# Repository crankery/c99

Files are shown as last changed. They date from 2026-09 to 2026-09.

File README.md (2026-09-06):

# Mini Mini Cortex 

***Note: Do not build this thing, I am just experimenting.***

Just a silly project really. Trying to squeeze Stuart Conner's [Mini Cortex](https://www.stuartconner.me.uk/mini_cortex/mini_cortex.htm) down
to a smaller form factor. Really, for no good reason.

I am going to attempt to add a different storage mechanism as CF cards are a bit hard to work with these days. To this end, there's an expansion
connector on this thing which is intended to have a stack of expansions plugged in from below.

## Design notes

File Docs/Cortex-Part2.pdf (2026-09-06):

# PROJECT

# CORTEX PART 2

# Build yourself a better brain: this month we explain the remaining Cortex circuitry and the construction of the main

board.

### Serial I/O on the Cortex is handled by a versatile

UART, the 9902. The CPU

### communicates with the UART via

its serial I/O bus, based on the

### Communication Register Unit or

CRU, which requires only three

### wires; thus the device fits easily

into an 18 -pin package. The 9902 is

### fully programmable and the range

### of variations is so great that it's

outside the scope of this article.
In the Cortex the chip is

### configured to handle RS232 eight -

bit codes with even parity and 1 stop bits; the communication rate can be set from BASIC using the

### BAUD command and the device is activated using the UNIT

statement. The parameter for

### UNIT is a 16 -bit word, each bit

### corresponding to a channel that

can be either on (1) or off (0).

### Channel 0 is the keyboard/ screen channel; channel 1 is the 9902 that is already wired into the

PCB. Channels 2-15 are

### implemented in software and only require the addition of extra

KEYBOARD
DATA
VALID
STROBE

INTEN i

LEVEL 4

IC 16b

## TABLE 1

| | TRANSFER | DIVISION | MONOSTABLE
SIZE | DDEN | RATE | RATIO | PERIOD | COMMENTS
| | (kHz) | (IC87) | (uS)
o | o | 125 | 12 | 3.0 | 51" single density
| 0 | 250 | 6 | 1.5 | 51" double density
o | | 250 | 6 | 1.5 | 8" single density
| | 500 | 3 | 0.75 | 8" double density

## BUYLINES

Powertran are supplying complete kits of parts and component packs for the Cortex. A complete 64K Cortex kit will cost £295 plus VAT, carriage free A ready -built 64K Cortex will cost £395 plus VAT, carriage free. Prices for addons (eg floppy discs, RS232C interface, memory expansion etc) and for component packs (eg PCB, semiconductors etc) can be found in Powertran's brochure. Powertran Cybernetics, Portway Industrial Estate, Andover, Hants SP10 2NM. Telephone 0264 64455.

9902s on the CRU bus. The Cortex powers up set to UNIT 1.
Executing UNIT 2 disables the

### keyboard and passes control to

the 9902. UNIT 3 enables both simultaneously.

SIZE
DENSITY

KEYBOARD DATA

+5V 0

R39
10k

(LSBI

D7 --- DO D6i- DI D5-- D2

D4--- D3
D3>~- D4
D2--- 05
01 | 06
DO | D7
(MSS)

R40

10k NC- DO
NC- D1
02

FDC INT

GNrD | s
7T | IC61a
CLK | Q YR

+5V

LEVEL 1

LEVEL 4

VDP
INT

IICC166cc/

IC76d/

D3
D4
D5
D6

BUS INT --- D7

LED4
TIME | R41 5VO- fr | 330R
CR | Q
IC61b
CS | Q

Fig. 1 Circuit diagram for the keyboard and control port.

ETI DECEMBER 1982

TO EN ---- SIZE .4 ⁻⁻ ROM

QO

Q1
02
03
Q4
05
BELL*-, D6
NC- 07

IC62

IC63

IC64

1
IORST

# _HOW IT WORKS -I/O

The I/O map space is split into two regions; the bottom region is for onboard I/O devices and the top region
causes an off -board access. (The CPU has an internal I/O area of 16 bits, some of which is reserved for specific hardware functions; the rest is free for the user.) The on -board I/O area of the Cortex is decoded by IC34 into eight 32 -bit slots, of which only four are used. Two slots (CS A and CS C) are used for the Asynchronous Communications Controllers (ACCs), the third (CS B) for the parallel I/O for the keyboard data, flags and control lines (such as 'ROM', mentioned in the Memory section), and the fourth for the DMA controller IC8 (CS D).

55

IC66a

1066ó

+5V 0

1142
6k8

R43
3k9

IC67

CLK | | XOUT
CS Al-c CS | CTS
CRU1N | CRUIN | RTS
A15 | CRUOUT | RIN
CRUCLK | CRUCLK
| aMIT | DSR
| Rÿ | A

A10
All
Al2>t
A13
A14

06

RLA

CLK--c 0

CS C
CRUIN/-- CRUIN
A15 | CRUOUT
CRUCLK-- CRUCLK
| C INT IC68

NO

TO
CASSETTE
MOTOR
-O D

IC69a

BELL

+5V 0--
+5V 0- | Q
CLK
K | Q

1C73a

XOUT - CTS o--- RTS

DSRD
RIN

IC74a

IC3b

TRANSMIT

IC74b)D | REQUEST TO SEND

IC71b

IC71c

C20 | R44
22n | 39k

-QC RC

IC70 8
A

+5V

IC71a

IC4c p- IC66b

CLK
K | p

IC73b

TERMINAL
READY | R53
| 100k

4 RECEIVE

IC71d

IC72c

R54
100k

R55
10k

### ___"vvvi cz4

+5V

R46
10k

# R48 - Bk2

R49
8k2
- _.4,./NAA/y

IC72a

R45
330R

, TO PIEZO
BUZZER

R50
C21 | Bk2

1on T

R51
1M0

IC72b

R52
^^k 10 | TAPE -6 " " 11" PLAYBACK

C22
330n
1

TAPE
RECORD
R47 | C23 100R | 10n

5n6 /7777

IC72 | p +12V PIN4 ,

IC72
PIN 11 1

+
C25
10u

77 - C26

T10u 4 -12V

Fig. 2 Circuit diagram of the RS232 and cassette interfaces.

## HOW IT WORKS - RS232 AND CASSETTE PORT

The RS232 port consists of IC68, a TMS9902 Asynchronous Communications Controller (ACC) and the TTL-to-RS232 signal level shifters (IC74a,b and IC71b,c). 1068 is a completely software -controlled device; its baud rate can be set at anything from 46 baud to over 100,000 baud. The number of bits to be transmitted or received can also be changed, as can the type, the parity and number of stop bits. The CPU drives the ACC through the serial I/O (CRU) bus. The ACC is decoded as a 32 -bit block, each bit being selected by the five address lines A10 -A14.
The cassette interface uses another ACC, IC67. First a 4.8kHz op -amp oscillator (IC72c) drives a level shifter (IC71d) before being divided by two in the first flip-flop (IC73a). This ensures that the waveform has a unity mark -space ratio. The serial output from IC67 then controls the action of the second flip-flop, IC73b, via the EXOR gate IC3b. When the output is high, IC73b acts as a shift register, passing through the 2.4 kHz tone; however, when the ACC output goes low then synchronously at the next clock pulse, IC73b starts to
divide | by | two, | hence | generating
1.2 kHz. The key point here is the synchronous switch from one tone to the other. The signal is high -pass -filtered and attenuated by R46, R47 and C23 betore passing to the tape recorder.
On playback the signal is first amplified by a factor of 100 and buffered in IC72b before going through an all -pass filter, IC72c. This is necessary because of the nature of tape recording.

When square waves are recorded on tape they are accurately captured;
however, | on | playback | frequency
equalisation is carried out in the tape recorder but the phase relationship is destroyed, resulting in a 'spiky' sine wave. This is corrected by the linear phase -shift -versus -frequency characteristic of the all -pass filter. Thus the original square wave shape is recovered at the output of IC72a. This is then level -shifted by IC71a and used to trigger a monostable (IC70a). At the end of the monostable period (312.5 uS) the state of the signal is sampled by the D -type flip -flip IC69a. As the half -periods of the two tones lie either side of the monostable period, each tone generates the opposite logic level at the sample point.

## HOW IT WORKS - FLOPPY DISC CONTROLLER

The TMS9909 (IC76) is a highly complex micro -controller, designed to work in

conjunction with the TMS9911 DMA controller to transfer data from floppy
discs. The FDC can control up to four drives which can be a mixture of two sizes or types.

All signals that go to the drives are open -collector buffered by IC80,82,83

and terminated by a resistor pack on the last drive in the chain. The signals from the drives are terminated on the board by a resistor pack and then buffered by IC84.

The raw data pulses from the drive, after being buffered by IC84a, are stretched by a monostable (IC70b) by an amount dependent on the data transfer

rate selected by the 'SIZE' I/O bit and the `DDEN' (double density enable) signal (see Table 1). The output of the monostable is used to control IC77, a digital phase -locked loop. The output of IC77 is, in the unlocked state, half the input clock frequency. When the loop is locked to a signal then the PLL inserts or deletes clock pulses in the pulse stream, thus shifting the average frequency. The programmable divider IC87 and divider IC69b are controlled by the 'SIZE' and 'DDEN' signals to select the correct clock frequency. The raw data is synchronised by IC88 to the PLL clock and then fed to the FDC. The FDC separates the interleaved clock and data bits from the pulse stream and sends data bytes via single byte DMA transfers to main memory.
Mini -floppy (5e) drives require a motor control signal to start and stop the disc rotating. Upon starting, the disc will not be ready for data transfers for one second while the disc gets up to speed. To reduce the time required to access the disc repeatedly IC79b keeps the motor running for five seconds after it is
de -selected and IC79a provides the initial one second 'not ready' signal to the FDC. For standard (8") drives that don't generate a 'ready' signal there is a set of four jumpers.

The BAsiC interpreter has a 'BOOT' command which causes the FDC to read the first track from disc 1 and execute it as a machine code program. This could,

for example, then search for and load the UCSD interpreter. In order that the system can boot from any type of disc there are two jumpers called 'SIZE' and 'DENSITY' which are read by IC63. This enables the BASIC interpreter to set up the FDC correctly.

56 | ETI DECEMBER 1982

# PROJECT: Cortex

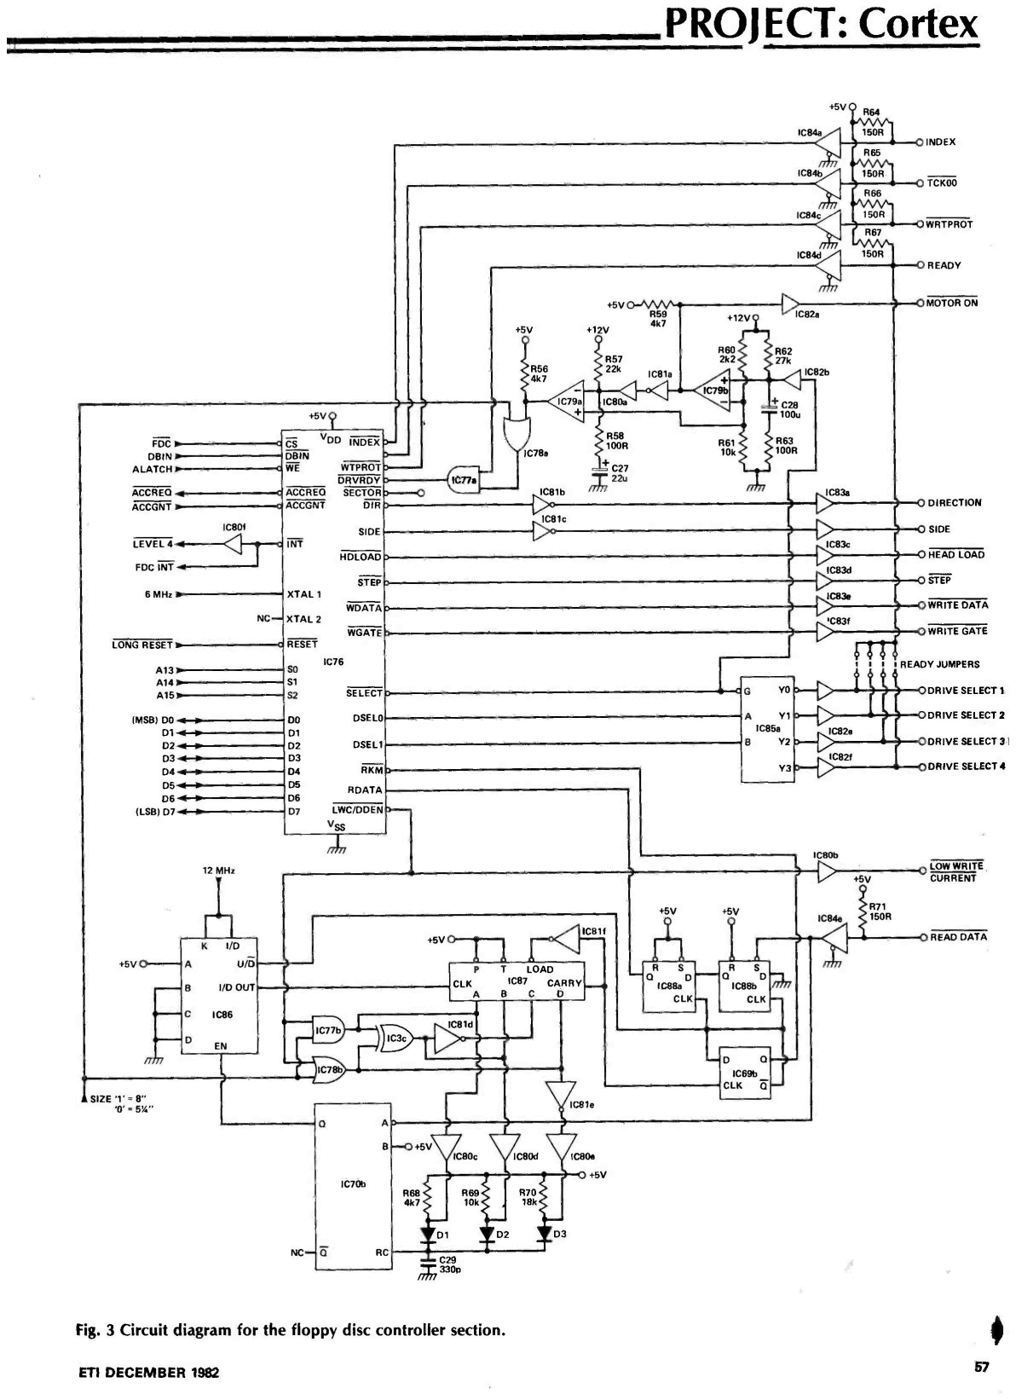
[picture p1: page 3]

IC84a

IC84b

IC84c

IC84c

+5V O -MN - R59

+5V | +12V | 4k7

R56
4k7

+5VQ

FDC | c CS | VDD INDEX
DBIN- | DBIN | r ALATCH | c WE | WTPROT D-
DRVRDY r ACCREO ,1. | c ACCREO | SECTOR r ACCGNT r | c ACCGNT | DIR

IC801
LEVEL 4

FDC INT

6MHzr

C

LONG RESET

NC-

A13 Jr
A14
A15

(MS81 DO I
D1 4
D2 4
D3 4
D4 4
D5 I
D6 4
(LOB) D7 4

12 MHz

+5V

K | I/D
A | U/D
B | I/D OUT

## te-C 1C86

D

AI SIZE 'V = 8"
0' = 5'/."

SIDE
INT
HO LOAD

XTAL 1

XTAL 2

RESET

IC76 SO

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
STEP

WDATA

WGATE

SELECT

DSE LO

DSEL1

RKM

RDATA

LWC/DDEN
Vss

(C770

L
II

IC78a

IC79a

IC81b

IC81c

22u

+12V

060
2k2
/ +

IC79b

R61
10k

IC82a

R62
27k

+ C28
100u

R63
1000
C G | 0
A | Yt
| IC85a
B | Y2
| Y3

IC82b

Y

IC81
+5V
ó1P | AIT | LOAD
CLK | IC87 | CARRY
A | BCD

IC706

A p

IC81d

IC81e

+5 V

R | S
- Q | D IC88a

CLK

+5V
Q

-0 INDEX

O TCK00

O WRTPROT

READY

O MOTOR ON

O DIRECTION

-0 SIDE

O HEAD LOAD

O STEP

O WRITE DATA

O WRITE GATE

bdd3 READY JUMPERS

IC82e

IC82f

ODRIVE SELECT 1

ODRIVE SELECT 2

ODRIVE SELECT 3

O DRIVE SELECT 4

IC80b
O LOW WRITE
+5V | CURRENT

IC84e

R S -Q D

ICBBb
- CLK

/777

-{D | O
I | IC69b
CLK
B | +5V
NC- Q | RC

R68
4k7
IC80c | V IC80d | V IC80e

D1

R69C | I | R70
10k< 1 | 18k
02 | D3

C29
?I/7 330p

0 +5V

071
150R

O READ DATA

Fig. 3 Circuit diagram for the floppy disc controller section.

ETI DECEMBER 1982 | 57

## TL^"E

## Lvvir

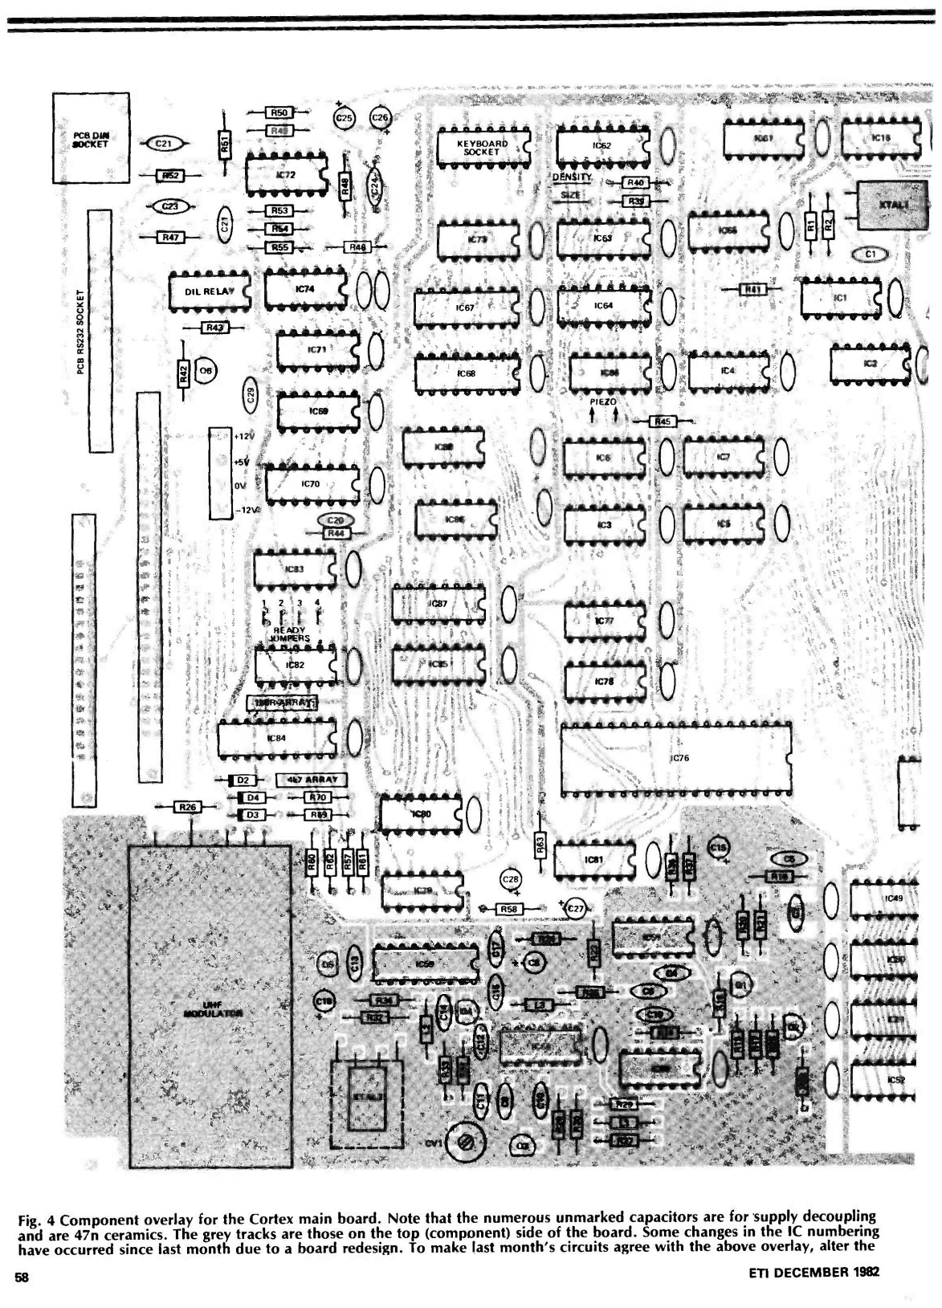
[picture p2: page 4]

PC6 DIN SOCKET

--{ R50..r---:

R19

IC7T
{E> | 4 R53 I--,.

F154

R46

[DIL RELAY

No L v v v
---I R43 F---
1
',IC)
T

.12Y

+5v

OV

-12V

cIC74 | to
IC71 | 0 v vvvv

s a a a a

IC6S

a e 1a an IC70

o

KEYBOARD SOCKET
b

73

1067

# n n a a awn

1C6ß
v

Ccoo

IC62

v v v DENSITY | R40

SIZE

# 0 vvbvvvw

C

C64 | 30

o

O

## avvvv PIEZO

tC61
9 | IC1 6

1065

t | t | R45
IC6 | 0
b | v
R44 | r | OCIC3O IC86

C20
v v v v
IC83 | 0
( | SOR ASH AY I

---{ D2 F-

R26}

n
--**3 V

IC

a a a 1111.131

IC78

-R4 --

an w a a n a a an q a w a a n n a

1C76 | (

O V Vº Vºººº Vº. V V p V Q Q v!

In

n w a w a

0 ¡ | IC81
v v v O v | :<ui
'Vt | oc::z:
0 \

11 Al1 .

# Laanaaaa

## V v vq v V

0

z9@ ¡'' V .

Fig. 4 Component overlay for the Cortex main board. Note that the numerous unmarked capacitors are for supply decoupling and are 47n ceramics. The grey tracks are those on the top (component) side of the board. Some changes in the IC numbering have occurred since last month due to a board redesign. To make last month's circuits agree with the above overlay, alter the

58 | ETl DECEMBER 1982

# PROJECT: Cortex

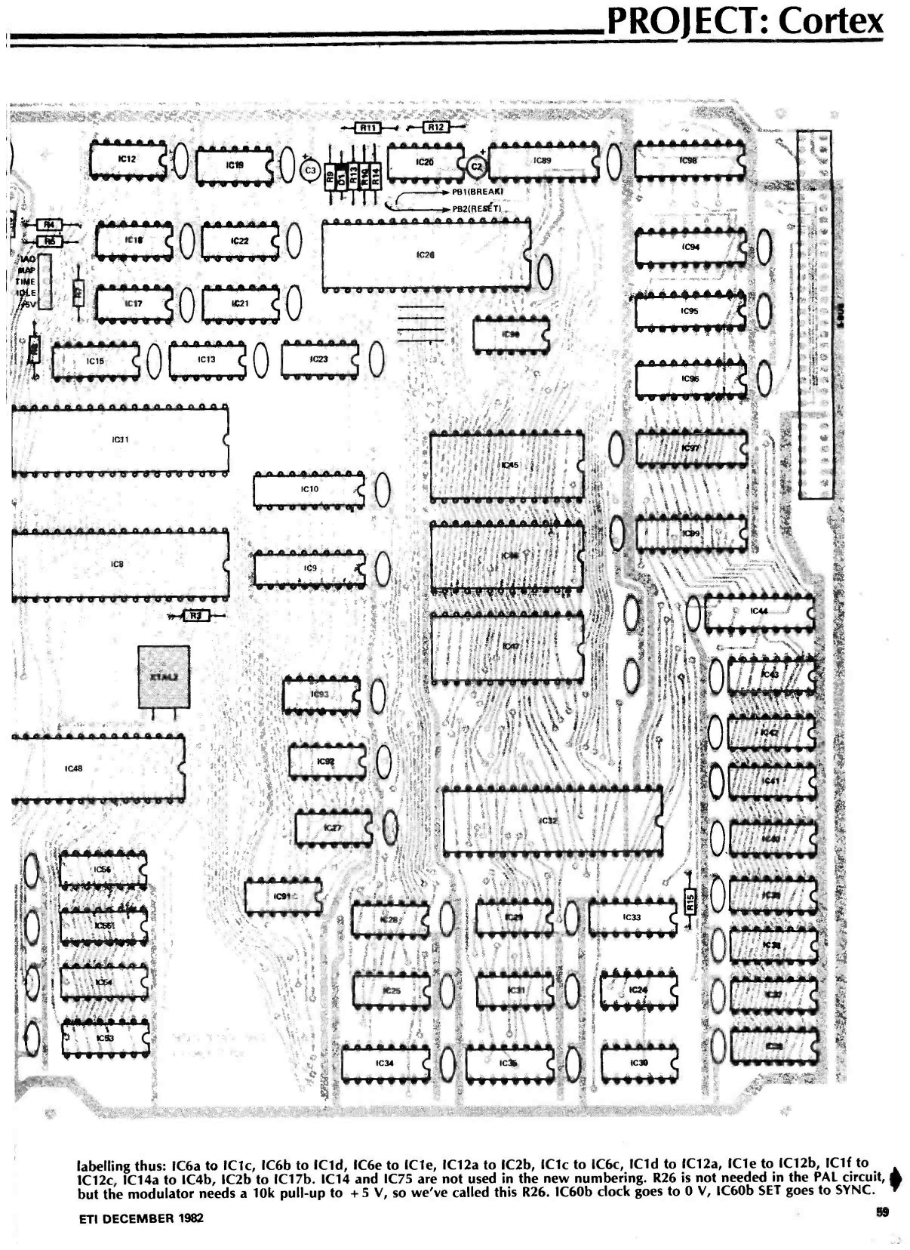
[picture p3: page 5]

1Ao
MAP
SINE
IDLE

ASV

A n n n

IC19
qrs vv v v
A A A A A | /' n AAA n A
'cut | r i | I. | Icº | (i
'U@ v V v | M V .. P0c. V

A A A` A A

1C17
V V v V v
n n A n A' L | G21

----.-*.i PB118REAKt

% . | >* PB2lREeET1_...
Ill | A A A A A A A n n A A n A A A A A
VA V VUUVWCOVVUUIWUVP | 0

*ervV 11v.

A n n A :.A...n | n n jk S A
L | IC13 | 4C23 | (
v V v v v v | v v v v v v

## pananAn GnAAnlfn AnAnn

IC11

Nr P V V V V a D V V D V V V V V D V V

---l R3 f

XTA12

QL

## nnsAAnn IC56

O L7:2

ICs3
L

p n n n Q

lrlj
vJvvv

n

1C26

r

IC90

p n A n A A A A A A A A n AI

KJl5

## JUVUVUVOUVOVUU

tana A. A A n A A o- n n

IC34 | 0

## VIIt(Iv very

te

tl ö

# ubs

0

labelling thus: lC6a to IC1c, IC6b to IC1d, lC6e to IC1e, IC12a to lC2b, IC1c to IC6c, lC1d to IC12a, !Cie to IC12b, IC1f to IC12c, IC14a to IC4b, lC2b to IC17b. 1C14 and IC75 are not used in the new numbering. R26 is not needed in the PAL circuit, but the modulator needs a 10k pull-up to +5 V, so we've called this R26. IC60b clock goes to 0 V, IC60b SET goes to SYNC.

ETI DECEMBER 1982 | 59

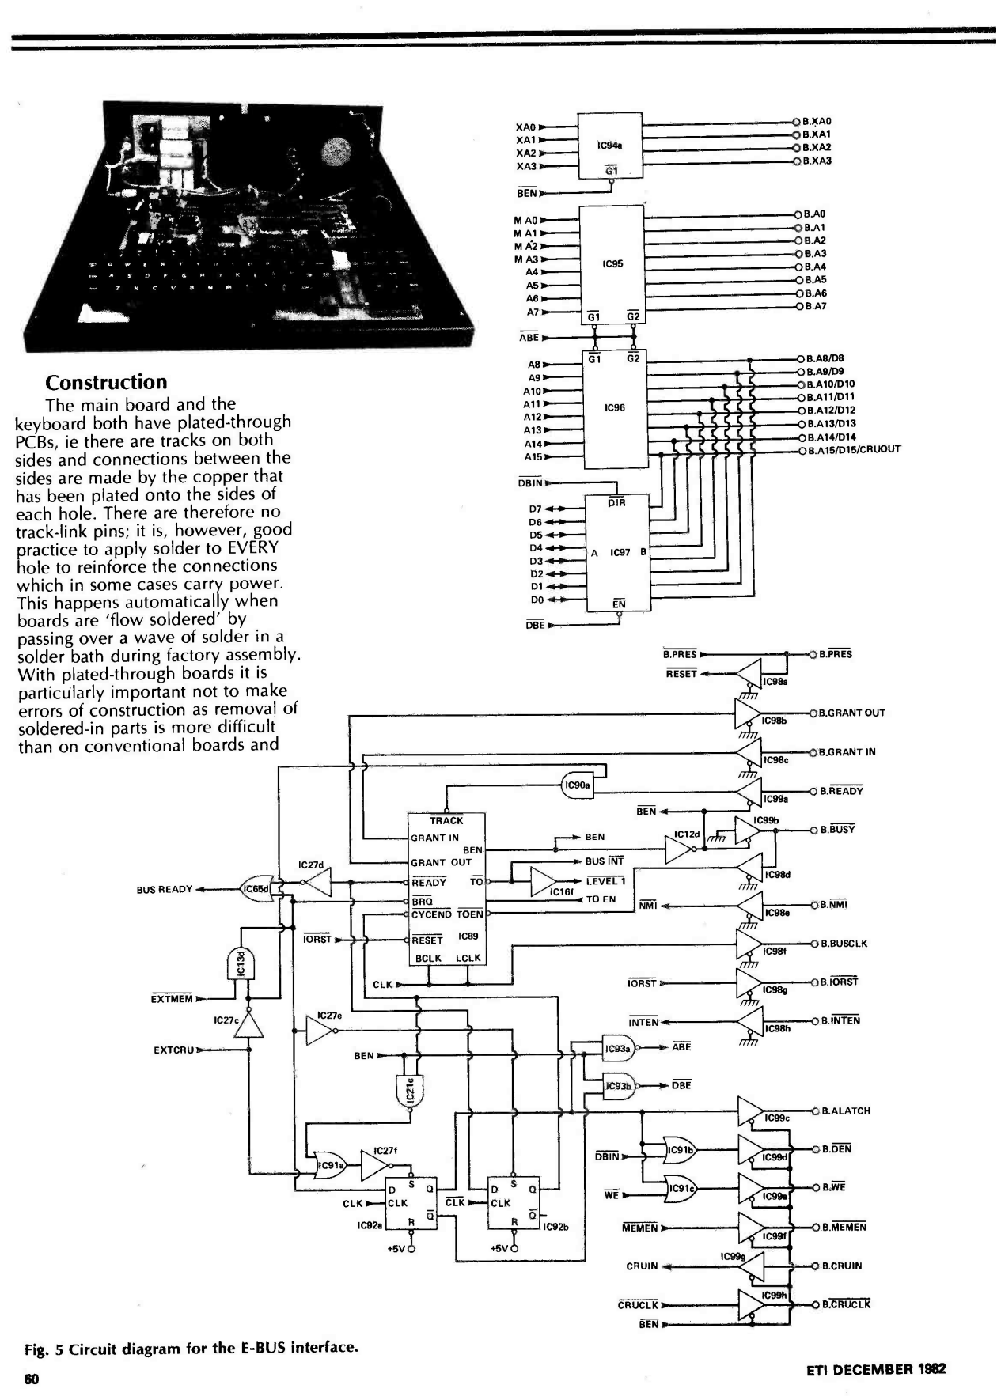
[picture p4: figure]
Construction The main board and the keyboard both have plated -through PCBs, ie there are tracks on both sides and connections between the sides are made by the copper that has been plated onto the sides of each hole. There are therefore no track -link pins; it is, however, good practice to apply solder to EVERY hole to reinforce the connections which in some cases carry power. This happens automatically when boards are 'flow soldered' by passing over a wave of solder in a solder bath during factory assembly. With plated -through boards it is particularly important not to make errors of construction as removal of soldered -in parts is more difficult than on conventional boards and; XAO XA1 XA2> XA3; BEN; ABE; O B.XAO; DBIN; DBE -; TRACK; GRANT IN; BEN GRANT OUT; READY; BRQ a CYCEND TOEN; RESET; BCLK; LCLK; CLK; -D CLK; DIR; O LAO; O B.AB/D8 O B.A9/D9 O B.A10/D10 OB.A11/D11 O B.Al2/D12 O B.A13/D13 OB.A14/D14 O B.A15/D15/CRUOUT; B.PRES; e B.PRES; O B.G RANT OUT 1C98b; OB.GRANT IN 1C98; O B.READY; B.BUSY; OB.NMI; BUS INT; NMI; IC98d LEVEL 1; IC16f tTOEN; O B.BUSC LK IC98f; IORST; O B.IORST IC989; INTEN; O B.INTEN IC98h; IC93b b-- DBE; B.ALATCH IC99c O; O B.DEN DB IN; MEMEN; O B.MEMEN; IC99g/ CRUIN; O B.CRUIN; CRUCLK; O B.CRUCLK; ETI DECEMBER 1982

Fig. 5 Circuit diagram for the E -BUS interface.

# PROJECT: Cortex

o

# Ping ® ® ® Wit

# ®;mm091mmmmmm Ned

# mm*m;mmmmmm*©o

# m!®*mi®+®;mm;m+m;o

# ®*mmmimm®;m®mm

21 | 22 | 23 | 24 | 25 | 26 | 27 | 28 | 29 | 30

NOTE:
ICI IS 74LS123
IC2 IS 74LS08
IC3 IS 74LS157
IC4 IS 2376
01 ISBC182L

C7
33p

R7
100k
31 | 140 | 2 | 3

9

V10 | Y9 | Y8 | Y7 | Y6 | Y5 | Y4 | V3 | Y2 | V1 | YO

38

PUSH
BUTTON.;

+5V 0

-12V 0

ovo

PB6I

REPEAT

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
> C7
> > ó

LJ
2
V

IC4

O ¢

2
O U
Q | m | (pJ
W | w Z | ¢ B1 LL | LL | LL

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
y C1 T 220n 1 C2

# T ²²⁰n

P655 SHIFT

18 | 17 18 | 120

PB66
SHIFT
tie/ o CONTROL

R1
4k7

R2
4k7

01

C5
220n

R4
12k
18k | | C3 | | C4
| | 4u7 | | 4u7
16 | 15 | 14 | 7 | 6

R3

VCC | 1RC 1C | 2RC | 2C
3
S 1CLR

11
2CLR | ICI | 16
20
2A
GND lA 2Q | 10 | 26
8 | ( 1 | ' 5 | 14 | 110

Fig. 6 Circuit diagram for the keyboard.

## HOW IT WORKS - E -BUS

4

2

5 16

R5
680k

R6
4k7

PB27

19 | 17

C6
4n7
0 +5V
1 | DO | 9
2 | D2 | 10
3 | STROBE | 11
4 | KEYDWN | 12
5 | -12V | 13
6 | OV | 14
7 | +5V | 15
8 | | 16

5

OIL SOCKET PIN OUT

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
07 LSB

4 | D6

13
| D5

12
| D4
| D3

10
0

D72

- r-- DO MSB

3
2

li

CAPS
LOCK

18 1
1A
S IC3

GND G

8 115

P84

+5V

R8
4k7

GRAPHICS

/7771

12

2

3
IC2a

The E -BUS is a powerful and com- pact bus which allows many intelligent

cards to share a common resource of memory and I/O cards. In order to share out the resources on the bus, each card has a priority according to its position. This is done by passing a signal down the bus which goes into each card as GRAN -TIN and comes out as GRANTOUT to form the GRANTIN of the next card. A second signal, BUSY, tells each card if the bus is in use or free. If the bus is free and a card requires the bus, it disables the lower priority cards with the GRAN -TOUT signal and if the GRANTIN signal and BUSY are OK it asserts BUSY and enables its data and address bus buffers.

Once the bus transfers are complete or if a higher priority card requires the

bus, then the card will relinquish con- trol. All these events are synchronised by

a backplane clock, BUSCLK. Each data transfer that takes place must signal its completion using READY.

The 74LS2001 gate array (IC89) contains the bus arbitration and control logic to gain and release the bus with timeouts upon error conditions. If the card cannot gain control of the bus after 128 clock cycles, it aborts with a timeout interrupt. Also, if after 16 clock cycles the transfer has not been signalled as complete using the READY line, the con- troller completes and issues a timeout

interrupt.
The E -BUS has provision for a multibit interrupt code signalled by the INTEN signal. This interface only provides a single interrupt level using the INTEN signal. The data, address and interrupt signal are multiplexed onto the same pins to conserve connections. The

ALATCH signal is used to enable the address latches when the address is on the bus. Then either DEN or WE will be signalled, to show that either a data read or write is occurring and that data is now on the bus. The INTEN signal can be

used to latch the interrupt code.

## KEYBOARD

KEYDWN

KEYBOARD
STROBE
The | keyboard is | a | separate | unit
providing a fully encoded output. Most of the work is carried out by the 2376
keyboard | encoder | (IC4). | This | IC
contains a 50 kHz oscillator and two ring counters of eight and 11 stages, the
outputs of which form an XY matrix across | which | the | switches | are

connected. By this means each key is sequentially scanned. The closing of one of the switches for a sufficient length of

time for switch bounce to be completed causes the scanning to stop; a 'valid'

signal now appears on the strobe output. The encoder also contains a 2376 -bit ROM (hence the IC name) arranged as three groups of 88 words of nine bits. The shift and control inputs select one of the three groups and the individual word is addressed by the ring counters.
IC3 is a data selector. D2 is either the output B6 or B8 depending on whether upper or lower case characters are selected by the CAPS LOCK switch. Repeated entry of a character is accomplished by multiple strobe signals from IC1, which is a dual monostable arranged as an oscillator and is enabled by a high level on the clear inputs.
ETI DECEMBER 1982 | 81

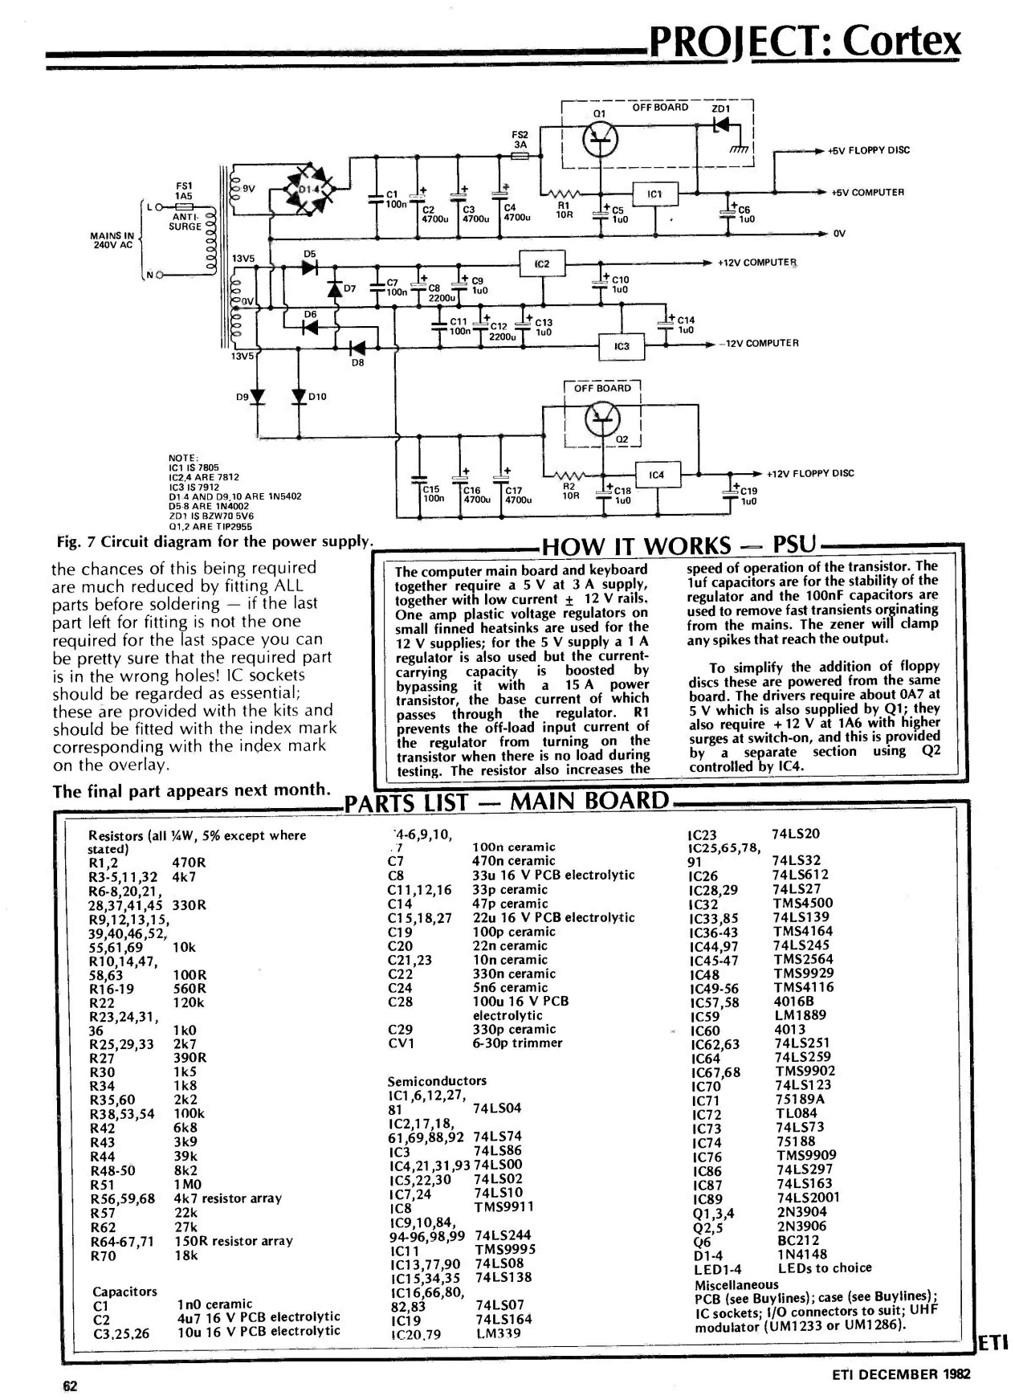
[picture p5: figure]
PROJECT: Cortex; ANTI- SURGE; MAINS IN 240V AC; NOTE: IC1 IS 7805 IC2 4 ARE 7812 IC3 IS 7912 D1-4 AND D9,10 ARE 1N5402 D5-8 ARE 1N4002 ZD1 IS BZW70 5V6 01,2 ARE TIP2955; the chances of this being required are much reduced by fitting ALL parts before soldering - if the last; part left for fitting is not the one required for the last space you can be pretty sure that the required part is in the wrong holes! IC sockets should be regarded as essential; these are provided with the kits and should be fitted with the index mark corresponding with the index mark on the overlay. The final part appears next month.; Resistors (all %W, 5% except where stated); 4k7 resistor array; 1513R resistor array; Capacitors; 1n0 ceramic; 4u7 16 V PCB electrolytic; 10u 16 V PCB electrolytic; 6TÚÜnT400uQOu; OFF BOARD; +12V COMPUTER; 12V COMPUTER; +5V FLOPPY DISC; +5V COMPUTER; +12V FLOPPY DISC HOW IT WORKS - PSU; The computer main board and keyboard together require a 5 V at 3 A supply, together with low current ± 12 V rails. One amp plastic voltage regulators on small finned heatsinks are used for the 12 V supplies; for the 5 V supply a 1 A; carrying; capacity; boosted; bypassing; with; power; transistor, the base current of which; passes; through; the; regulator.; prevents the off-load input current of; the regulator from turning on; transistor when there is no load during; regulator and the 100nF capacitors are; from the mains. The zener will clamp any spikes that reach the output.; To simplify the addition of floppy discs these are powered from the same board. The drivers require about 0A7 at 5 V which is also supplied by Q1; they also require +12 V at 1A6 with higher; separate; section; using; controlled by 1C4.; PARTS LIST - MAIN BOARD; 100n ceramic 470n ceramic 33u 16 V PCB electrolytic 33p ceramic 47p ceramic 22u 16 V PCB electrolytic 100p ceramic 22n ceramic 10n ceramic 330n ceramic 5n6 ceramic 100u16VPCB electrolytic 330p ceramic 6-30p trimmer; Semiconductors IC1,6,12,27,; 74LSO4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

Fig. 7 Circuit diagram for the power supply.

regulator is also used but the current -

testing. The resistor also increases the speed of operation of the transistor. The 1 of capacitors are for the stability of the

used to remove fast transients orginating

surges at switch -on, and this is provided

PCB (see Buylines); case (see Buylines);

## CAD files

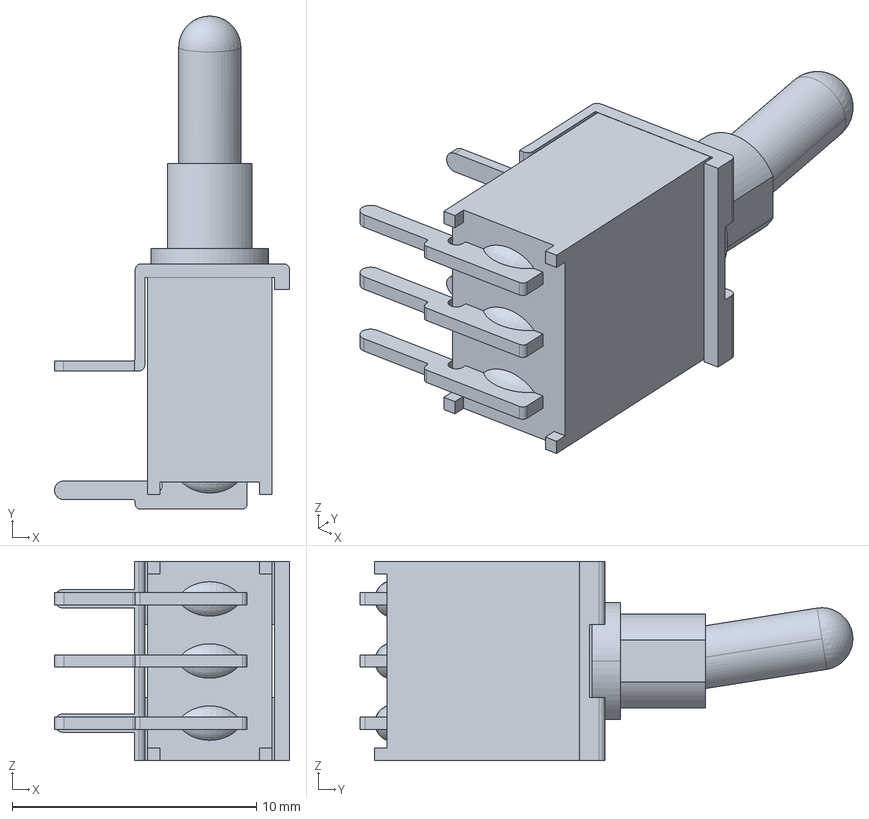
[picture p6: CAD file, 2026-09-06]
3D/toggle_switch_2as1t2a1m6qes.stp
9.63 x 20.2 x 8.15 mm

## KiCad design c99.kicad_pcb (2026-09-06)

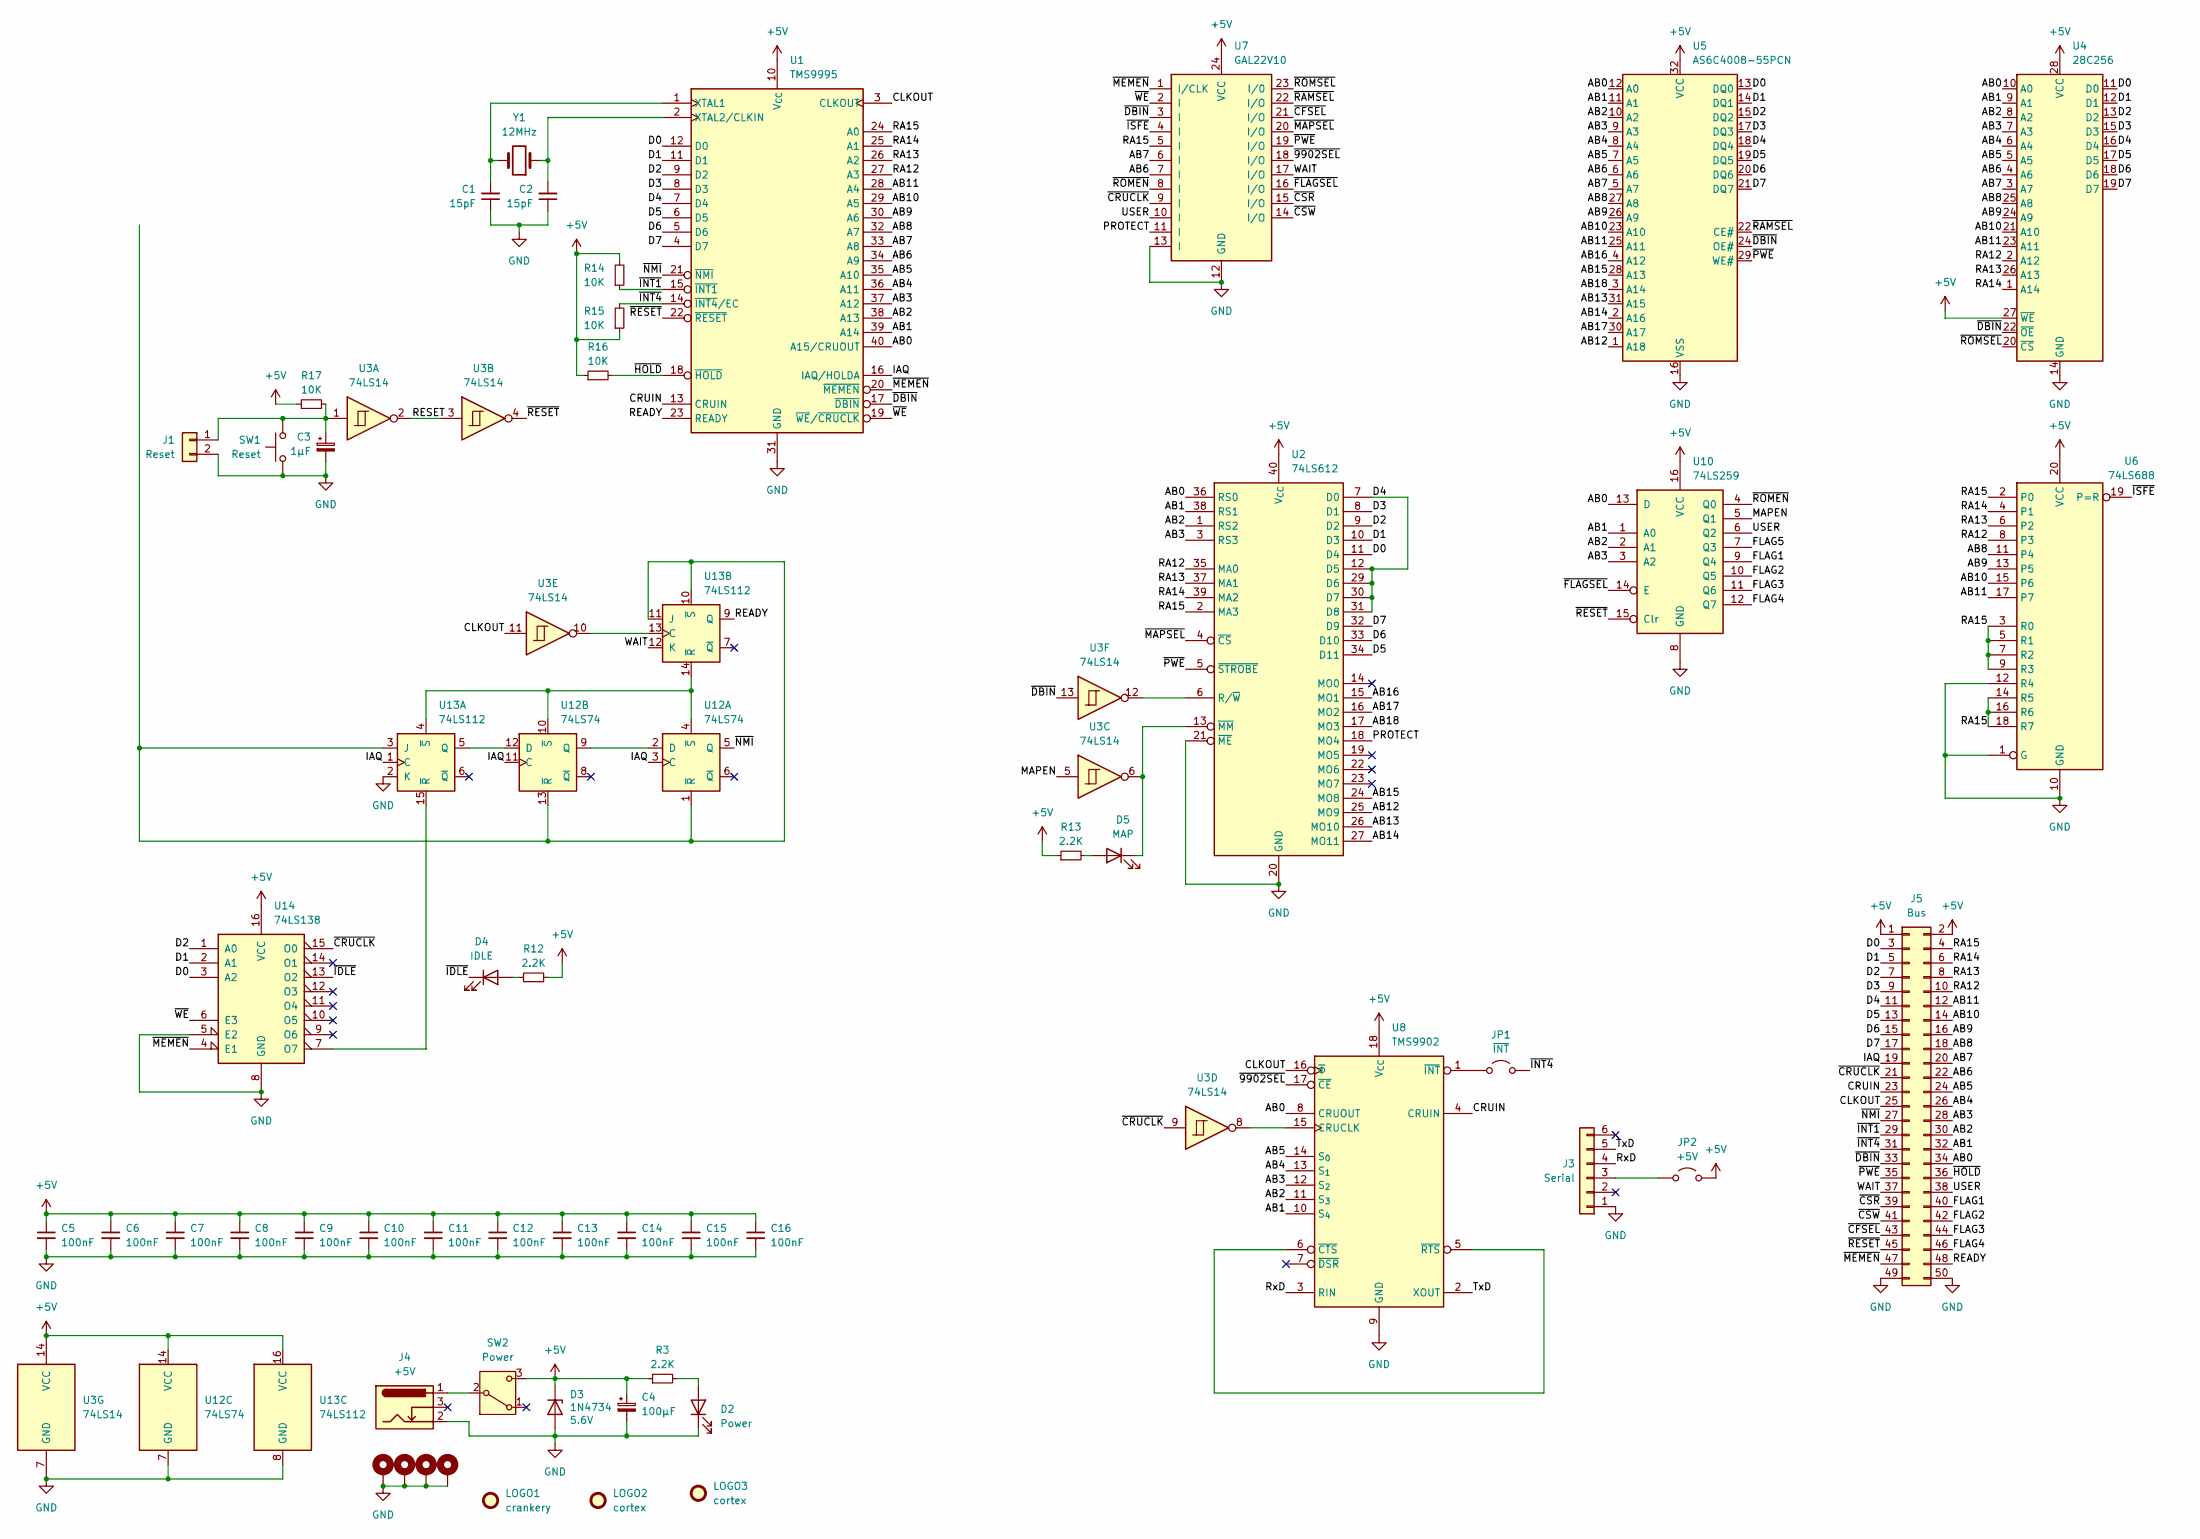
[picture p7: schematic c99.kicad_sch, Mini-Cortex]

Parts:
C1, C2: 15pF; C_Disc_D4.3mm_W1.9mm_P5.00mm
C3: 1µF; CP_Radial_D5.0mm_P2.00mm
C4: 100µF; CP_Radial_D5.0mm_P2.00mm
C5, C6, C7, C8, C9, C10, C11, C12, C13, C14, C15, C16: 100nF; C_Disc_D4.3mm_W1.9mm_P5.00mm
D2: Power; LED_D3.0mm
D3: 1N4734; D_DO-41_SOD81_P7.62mm_Horizontal
D4: IDLE; LED_D3.0mm
D5: MAP; LED_D3.0mm
H1, H2, H3, H4: MountingHole_Pad; MountingHole_2.7mm_M2.5_DIN965_Pad
J1: Reset; JST_PH_B2B-PH-K_1x02_P2.00mm_Vertical
J3: Serial; PinSocket_1x06_P2.54mm_Horizontal
J4: +5V; BarrelJack_Horizontal
J5: Bus; PinHeader_2x25_P2.54mm_Vertical
JP1: ~{INT}; PinHeader_1x02_P2.54mm_Vertical
JP2: +5V; PinHeader_1x02_P2.54mm_Vertical
LOGO1: crankery; crankery_small
LOGO2: cortex
LOGO3: cortex; eti
R3, R12, R13: 2.2K; R_Axial_DIN0204_L3.6mm_D1.6mm_P5.08mm_Horizontal
R14, R15, R16, R17: 10K; R_Axial_DIN0204_L3.6mm_D1.6mm_P5.08mm_Horizontal
SW1: Reset; SW_Tactile_SPST_Angled_PTS645Vx39-2LFS
SW2: Power; SW_2AS1T2A1M6QES
U1: TMS9995; DIP-40_W15.24mm
U2: 74LS612; DIP-40_W15.24mm
U3: 74LS14; DIP-14_W7.62mm
U4: 28C256; DIP-28_W15.24mm
U5: AS6C4008-55PCN; DIP-32_W15.24mm
U6: 74LS688; DIP-20_W7.62mm
U7: GAL22V10; DIP-24_W7.62mm
U8: TMS9902; DIP-18_W7.62mm
U10: 74LS259; DIP-16_W7.62mm
U12: 74LS74; DIP-14_W7.62mm
U13: 74LS112; DIP-16_W7.62mm
U14: 74LS138; DIP-16_W7.62mm
Y1: 12MHz; Crystal_HC49-U_Vertical

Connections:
+5V: C4.1, C5.1, C6.1, C7.1, C8.1, C9.1, C10.1, C11.1, C12.1, C13.1, C14.1, C15.1, C16.1, D3.1 (K), J5.1, J5.2, JP2.2 (B), R3.1, R12.1, R13.1, R14.2, R15.1, R16.1, R17.1, SW2.3 (C), U1.10 (V_{CC}), U2.40 (V_{CC}), U3.14 (VCC), U4.27 (~WE), U4.28 (VCC), U5.32 (VCC), U6.20 (VCC), U7.24 (VCC), U8.18 (V_{CC}), U10.16 (VCC), U12.14 (VCC), U13.16 (VCC), U14.16 (VCC)
/AB0: J5.34, U1.40 (A15/CRUOUT), U2.36 (RS0), U4.10 (A0), U5.12 (A0), U8.8 (CRUOUT), U10.13 (D)
/AB1: J5.32, U1.39 (A14), U2.38 (RS1), U4.9 (A1), U5.11 (A1), U8.10 (S_{4}), U10.1 (A0)
/AB2: J5.30, U1.38 (A13), U2.1 (RS2), U4.8 (A2), U5.10 (A2), U8.11 (S_{3}), U10.2 (A1)
/AB3: J5.28, U1.37 (A12), U2.3 (RS3), U4.7 (A3), U5.9 (A3), U8.12 (S_{2}), U10.3 (A2)
/AB4: J5.26, U1.36 (A11), U4.6 (A4), U5.8 (A4), U8.13 (S_{1})
/AB5: J5.24, U1.35 (A10), U4.5 (A5), U5.7 (A5), U8.14 (S_{0})
/AB6: J5.22, U1.34 (A9), U4.4 (A6), U5.6 (A6), U7.7 (I)
/AB7: J5.20, U1.33 (A8), U4.3 (A7), U5.5 (A7), U7.6 (I)
/AB8: J5.18, U1.32 (A7), U4.25 (A8), U5.27 (A8), U6.11 (P4)
/AB9: J5.16, U1.30 (A6), U4.24 (A9), U5.26 (A9), U6.13 (P5)
/AB10: J5.14, U1.29 (A5), U4.21 (A10), U5.23 (A10), U6.15 (P6)
/AB11: J5.12, U1.28 (A4), U4.23 (A11), U5.25 (A11), U6.17 (P7)
/AB12: U2.25 (MO9), U5.1 (A18)
/AB13: U2.26 (MO10), U5.31 (A15)
/AB14: U2.27 (MO11), U5.2 (A16)
/AB15: U2.24 (MO8), U5.28 (A13)
/AB16: U2.15 (MO1), U5.4 (A12)
/AB17: U2.16 (MO2), U5.30 (A17)
/AB18: U2.17 (MO3), U5.3 (A14)
/CLKOUT: J5.25, U1.3 (CLKOUT), U3.11, U8.16 (~Φ)
/CRUIN: J5.23, U1.13 (CRUIN), U8.4 (CRUIN)
/D0: J5.3, U1.12 (D0), U2.11 (D4), U4.11 (D0), U5.13 (DQ0), U14.3 (A2)
/D1: J5.5, U1.11 (D1), U2.10 (D3), U4.12 (D1), U5.14 (DQ1), U14.2 (A1)
/D2: J5.7, U1.9 (D2), U2.9 (D2), U4.13 (D2), U5.15 (DQ2), U14.1 (A0)
/D3: J5.9, U1.8 (D3), U2.8 (D1), U4.15 (D3), U5.17 (DQ3)
/D4: J5.11, U1.7 (D4), U2.7 (D0), U2.12 (D5), U2.29 (D6), U2.30 (D7), U2.31 (D8), U4.16 (D4), U5.18 (DQ4)
/D5: J5.13, U1.6 (D5), U2.34 (D11), U4.17 (D5), U5.19 (DQ5)
/D6: J5.15, U1.5 (D6), U2.33 (D10), U4.18 (D6), U5.20 (DQ6)
/D7: J5.17, U1.4 (D7), U2.32 (D9), U4.19 (D7), U5.21 (DQ7)
/FLAG1: J5.40, U10.9 (Q4)
/FLAG2: J5.42, U10.10 (Q5)
/FLAG3: J5.44, U10.11 (Q6)
/FLAG4: J5.46, U10.12 (Q7)
/FLAG5: U10.7 (Q3)
/IAQ: J5.19, U1.16 (IAQ/HOLDA), U12.3 (C), U12.11 (C), U13.1 (C)
/MAPEN: U3.5, U10.5 (Q1)
/PROTECT: U2.18 (MO4), U7.11 (I)
/RA12: J5.10, U1.27 (A3), U2.35 (MA0), U4.2 (A12), U6.8 (P3)
/RA13: J5.8, U1.26 (A2), U2.37 (MA1), U4.26 (A13), U6.6 (P2)
/RA14: J5.6, U1.25 (A1), U2.39 (MA2), U4.1 (A14), U6.4 (P1)
/RA15: J5.4, U1.24 (A0), U2.2 (MA3), U6.2 (P0), U6.3 (R0), U6.5 (R1), U6.7 (R2), U6.9 (R3), U6.14 (R5), U6.16 (R6), U6.18 (R7), U7.5 (I)
/READY: J5.48, U1.23 (READY), U13.9 (Q)
/RESET: U3.2, U3.3
/RxD: J3.4, U8.3 (RIN)
/TxD: J3.5, U8.2 (XOUT)
/USER: J5.38, U7.10 (I), U10.6 (Q2)
/WAIT: J5.37, U7.17 (I/O), U13.12 (K)
/~9902SEL: U7.18 (I/O), U8.17 (~CE)
/~CFSEL: J5.43, U7.21 (I/O)
/~CRUCLK: J5.21, U3.9, U7.9 (I), U14.15 (O0)
/~CSR: J5.39, U7.15 (I/O)
/~CSW: J5.41, U7.14 (I/O)
/~DBIN: J5.33, U1.17 (~DBIN), U3.13, U4.22 (~OE), U5.24 (OE#), U7.3 (I)
/~FLAGSEL: U7.16 (I/O), U10.14 (E)
/~HOLD: J5.36, R16.2, U1.18 (~HOLD)
/~IDLE: D4.1 (K), U14.13 (O2)
/~INT1: J5.29, R14.1, U1.15 (~INT1)
/~INT4: J5.31, JP1.2 (B), R15.2, U1.14 (~INT4/EC)
/~ISFE: U6.19 (P=R), U7.4 (I)
/~MAPSEL: U2.4 (~CS), U7.20 (I/O)
/~MEMEN: J5.47, U1.20 (~MEMEN), U7.1 (I/CLK), U14.4 (E1)
/~NMI: J5.27, U1.21 (~NMI), U12.5 (Q)
/~PWE: J5.35, U2.5 (~STROBE), U5.29 (WE#), U7.19 (I/O)
/~RAMSEL: U5.22 (CE#), U7.22 (I/O)
/~RESET: J5.45, U1.22 (~RESET), U3.4, U10.15 (Clr)
/~ROMEN: U7.8 (I), U10.4 (Q0)
/~ROMSEL: U4.20 (~CS), U7.23 (I/0)
/~WE: U1.19 (~WE/~CRUCLK), U7.2 (I), U14.6 (E3)
GND: C1.1, C2.1, C3.2, C4.2, C5.2, C6.2, C7.2, C8.2, C9.2, C10.2, C11.2, C12.2, C13.2, C14.2, C15.2, C16.2, D2.1 (K), D3.2 (A), H1.1 (1_1), H2.1 (1_1), H3.1 (1_1), H4.1 (1_1), J1.2, J3.1, J4.2, J5.49, J5.50, SW1.1, U1.31 (GND), U2.20 (GND), U2.21 (~ME), U3.7 (GND), U4.14 (GND), U5.16 (VSS), U6.1 (G), U6.10 (GND), U6.12 (R4), U7.12 (GND), U7.13 (I), U8.9 (GND), U10.8 (GND), U12.7 (GND), U13.2 (K), U13.8 (GND), U14.5 (E2), U14.8 (GND)
unnamed: D2.2 (A), R3.2
unnamed: D4.2 (A), R12.2
unnamed: D5.2 (A), R13.2
unnamed: D5.1 (K), U2.13 (~MM), U3.6
unnamed: C3.1, J1.1, R17.2, SW1.2, U3.1
unnamed: J3.3, JP2.1 (A)
unnamed: JP1.1 (A), U8.1 (~INT)
unnamed: J4.1, SW2.2 (B)
unnamed: C1.2, U1.1 (XTAL1), Y1.2
unnamed: C2.2, U1.2 (XTAL2/CLKIN), Y1.1
unnamed: U2.6 (R/~W), U3.12
unnamed: U3.8, U8.15 (CRUCLK)
unnamed: U8.5 (~RTS), U8.6 (~CTS)
unnamed: U12.2 (D), U12.9 (Q)
unnamed: U12.1 (~R), U12.13 (~R), U13.3 (J), U13.10 (~S), U13.11 (J)
unnamed: U12.4 (~S), U12.10 (~S), U13.4 (~S), U13.14 (~R)
unnamed: U12.12 (D), U13.5 (Q)
unnamed: U13.15 (~R), U14.7 (O7)
unnamed: U3.10, U13.13 (C)

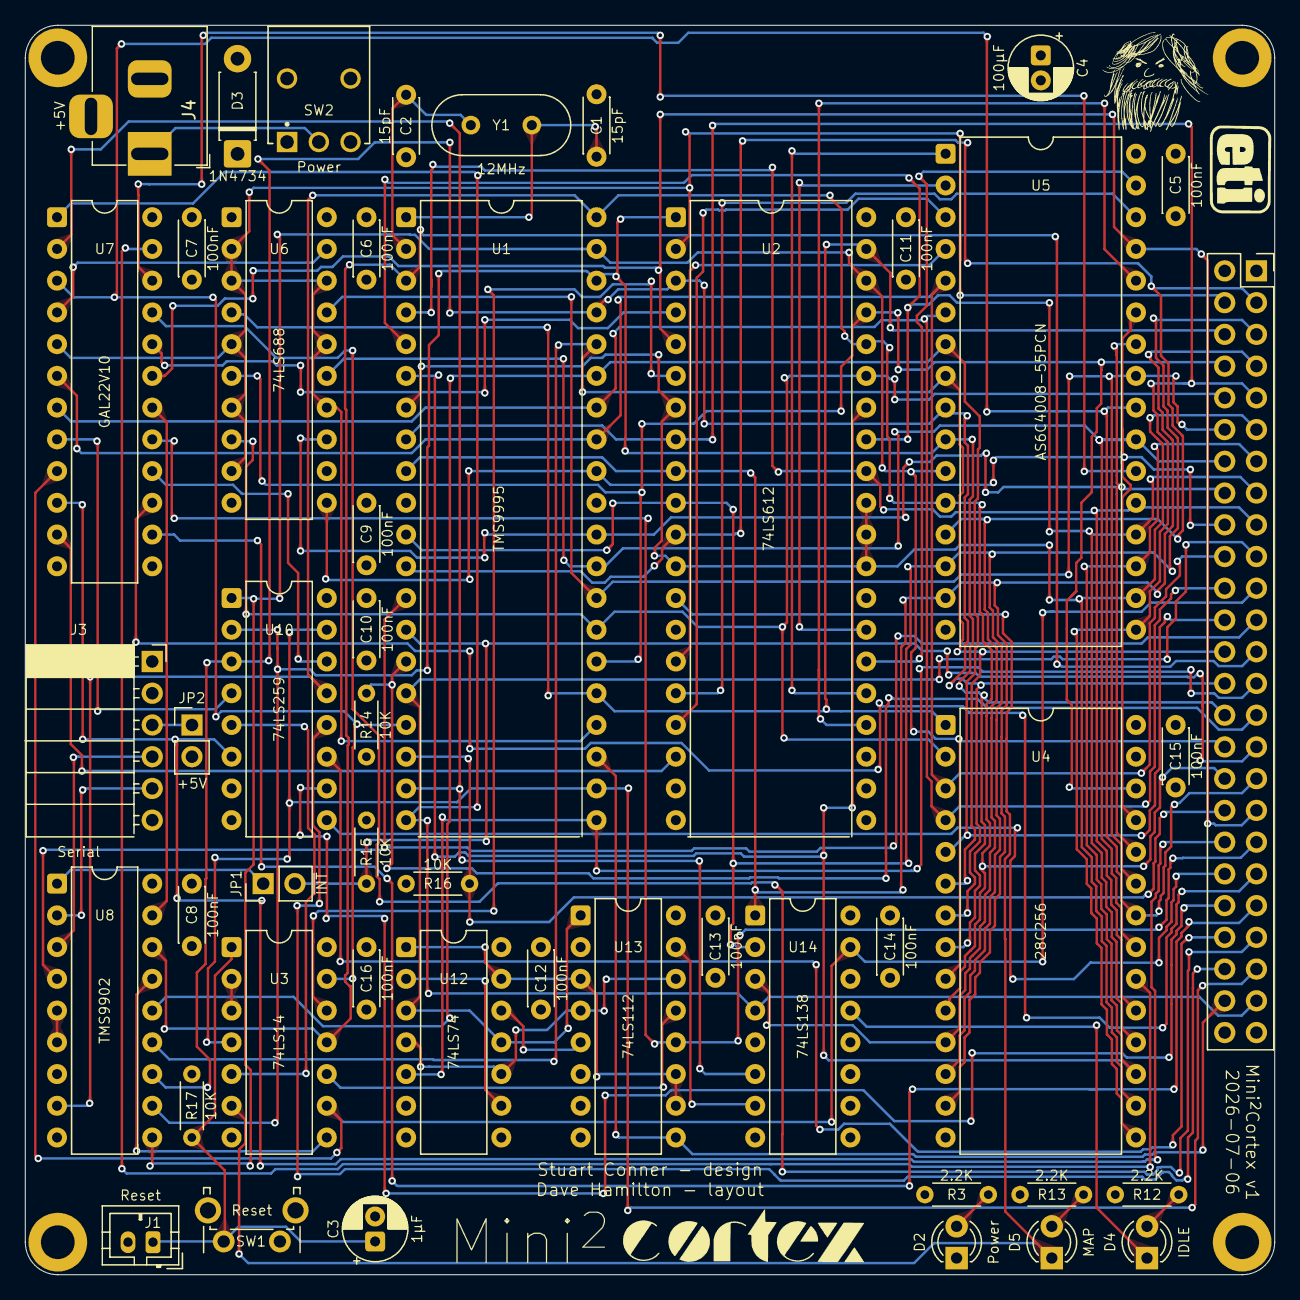
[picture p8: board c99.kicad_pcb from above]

Board: 4 copper layers, 100.0 x 100.0 mm, 55 parts (1 on the bottom side), 88 nets.

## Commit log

2026-09-06 initial commit (routing complete)
    [c99.kicad_pcb, c99.kicad_sch, toggle_switch_2as1t2a1m6qes.stp]
2026-09-06 silkscreen fixups
    [c99.kicad_pcb, c99.kicad_sch]
